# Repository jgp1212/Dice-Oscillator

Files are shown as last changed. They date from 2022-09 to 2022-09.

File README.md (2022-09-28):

# Dice-Oscillator
A simple pcb design for a 40106 square wave oscillator drone.



NOTE: This Readme is still a work in progress

Control 6 oscillators using 6 potentiometers. 


Additional pins have been exposed to allow for potential vactrol implementations, or maybe you have a potentiometer that doesnt fit the footprint. 
Use cables to solder to these points.


Can be powered by 5-12V, using 5V will output roughly ~4Vpp, while 12V will output a 10Vpp.
Power supply must be center positive, I have blown up several CD40106BE by accident by using center negative by accident.

BOM:
-  1 x CD40106BE IC
  - 

-  1 x 2.1mm Power jack OR 1 x 16 pin eurorackstyle header. USE ONLY ONE OPTION WHEN POWERING.
  - 

-  7 x 10K Ohm Resistors
-  1 x 8.2K Ohm Resistor
-  6 x 10K Potentiometers
-  6 x 4.7uF Capacitors (can be altered for different audio)
-  6 x 2 pin jumpers. OR 6 toggle switches whch can be wired in place of the jumpers.

-  1 x LED
-  1 x 510Ohm Resistor
-  1 x 3.5mm mono jack (WQP-PJ301M-12_JACK from Thonkiconn)
  -

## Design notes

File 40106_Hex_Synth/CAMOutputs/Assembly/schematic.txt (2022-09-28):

Partlist exported from C:/Users/jiyong_park/Documents/EAGLE/projects/40106_Hex_Synth/schematic.sch at 16/09/2022 11:22 PM

Qty Value          Device                          Package                    Parts                          Description                                                                                                     AVAILABILITY DESCRIPTION                                               MF                MP        PACKAGE                   POPULARITY PRICE PROD_ID    PURCHASE-URL                                               SF_SKU    VALUE
6                  C5/5                            C5B5                       C1, C2, C3, C4, C5, C6         CAPACITOR                                                                                                                                                                                                                                    1                                                                                                     
8                  CONN_02                         1X02                       J1, J2, J3, J4, J5, J6, J7, J8 Multi connection point. Often used as Generic Header-pin footprint for 0.1 inch spaced/style header connections                                                                                                                                                                                                                                    
6                  CONN_03                         1X03                       J9, J10, J11, J12, J13, J14    Multi connection point. Often used as Generic Header-pin footprint for 0.1 inch spaced/style header connections                                                                                                                                                                                                                                    
1                  LED5MM                          LED_5MM                    D2                             LED (Generic)                                                                                                                                                                                                                                                                                                                                      
1                  SWITCH-SPDT-PTH-11.6X4.0MM      SWITCH_SPDT_PTH_11.6X4.0MM S1                             Single Pole, Double Throw (SPDT) Switch                                                                                                                                                                                                                       SWCH-08261                                                            COM-00102      
2                  RESISTORAXIAL-0.3               AXIAL-0.3                  8.2K, 510OHM                   Generic Resistor Package                                                                                                                                                                                                                                                                                                                           
7   10k            10KOHM-HORIZ-1/4W-1%            AXIAL-0.3                  R1, R2, R3, R4, R5, R6, R7     10kΩ resistor                                                                                                                                                                                                                                                 RES-12183                                                                       10k  
6   10k            POTENTIOMETER-PTH-9MM-1/20W-20% POT-PTH-ALPS               VR1, VR2, VR3, VR4, VR5, VR7   Potentiometer (Pot)                                                                                                                                                                                                                                           RES-09177                                                             COM-09288 10k  
1   CD40106BE      CD40106BE                       DIP794W45P254L1969H508Q14  U1                             Check availability                                                                                              In Stock      6-ch, 3-V to 18-V inverters with Schmitt-Trigger inputs  Texas Instruments CD40106BE PDIP-14 Texas Instruments            None             https://pricing.snapeda.com/search/part/CD40106BE/?ref=eda                
1   POWER_JACK     POWER_JACK                      POWER_JACK_PTH             J15                            Power Jack Connector                                                                                                                                                                                                                                          CONN-08197                                                                           
1   POWER_SIMPLE16 POWER_SIMPLE16                  POWER_16                   U$1

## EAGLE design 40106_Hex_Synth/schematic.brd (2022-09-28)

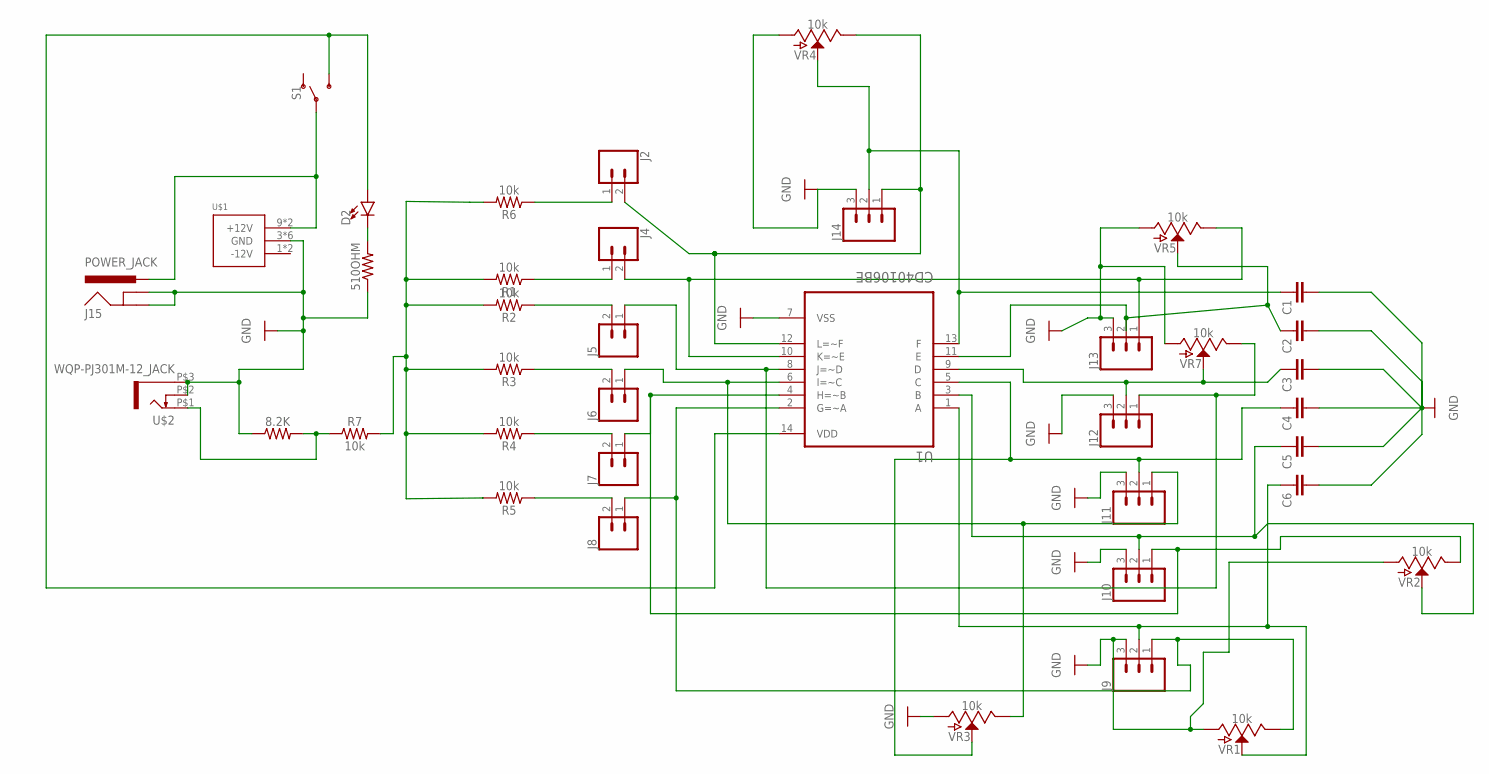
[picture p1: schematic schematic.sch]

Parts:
8.2K, 510OHM: AXIAL-0.3
C1, C2, C3, C4, C5, C6: C5/5; C5B5
D2: LED5MM; LED_5MM
J2, J4, J5, J6, J7, J8: CONN_02; 1X02
J9, J10, J11, J12, J13, J14: CONN_03; 1X03
J15: POWER_JACK; POWER_JACK_PTH
R1, R2, R3, R4, R5, R6, R7: 10k; AXIAL-0.3
S1: SWITCH-SPDT-PTH-11.6X4.0MM; SWITCH_SPDT_PTH_11.6X4.0MM
U1: CD40106BE; DIP794W45P254L1969H508Q14
U$1: POWER_SIMPLE16; POWER_16
U$2: WQP-PJ301M-12_JACK
VR1, VR2, VR3, VR4, VR5, VR7: 10k; POT-PTH-ALPS

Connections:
GND: 8.2K.P$1 (1), 510OHM.P$1 (1), C1.2, C2.2, C3.2, C4.2, C5.2, C6.2, J9.3, J10.3, J11.3, J12.3, J13.3, J14.3, J15.GND, J15.GNDBREAK, U1.7 (VSS), U$1.3 (GND), U$1.4 (GND), U$1.5 (GND), U$1.6 (GND), U$1.7 (GND), U$1.8 (GND), U$2.P$2 (3), U$2.P$3 (1), VR1.P$3 (A), VR2.P$3 (A), VR3.P$3 (A), VR4.P$3 (A), VR5.P$3 (A), VR7.P$3 (A)
unnamed: 510OHM.P$2 (2), D2.K (C)
unnamed: C1.1, J14.2, U1.13 (F), VR4.P$2 (S)
unnamed: J2.2, J14.1, U1.12 (L=~F), VR4.P$1 (E)
unnamed: J4.1, R1.P$1 (1)
unnamed: J5.1, J12.1, U1.8 (J=~D), VR7.P$1 (E)
unnamed: C4.1, J11.2, U1.5 (C), VR3.P$2 (S)
unnamed: C5.1, J10.2, U1.3 (B), VR2.P$2 (S)
unnamed: C6.1, J9.2, U1.1 (A), VR1.P$2 (S)
unnamed: C2.1, J13.2, U1.11 (E), VR5.P$2 (S)
unnamed: J5.2, R2.P$1 (1)
unnamed: J8.2, R5.P$1 (1)
unnamed: J7.2, R4.P$1 (1)
unnamed: J6.2, R3.P$1 (1)
unnamed: J2.1, R6.P$1 (1)
unnamed: J4.2, J13.1, U1.10 (K=~E), VR5.P$1 (E)
unnamed: C3.1, J12.2, U1.9 (D), VR7.P$2 (S)
unnamed: J6.1, J11.1, U1.6 (I=~C), VR3.P$1 (E)
unnamed: J7.1, J10.1, U1.4 (H=~B), VR2.P$1 (E)
unnamed: J8.1, J9.1, U1.2 (G=~A), VR1.P$1 (E)
unnamed: 8.2K.P$2 (2), R7.P$1 (1), U$2.P$1 (2)
unnamed: R1.P$2 (2), R2.P$2 (2), R3.P$2 (2), R4.P$2 (2), R5.P$2 (2), R6.P$2 (2), R7.P$2 (2)
unnamed: J15.PWR, S1.2, U$1.9 (+12V), U$1.10 (+12V)
unnamed: D2.A, S1.3 (S), U1.14 (VDD)

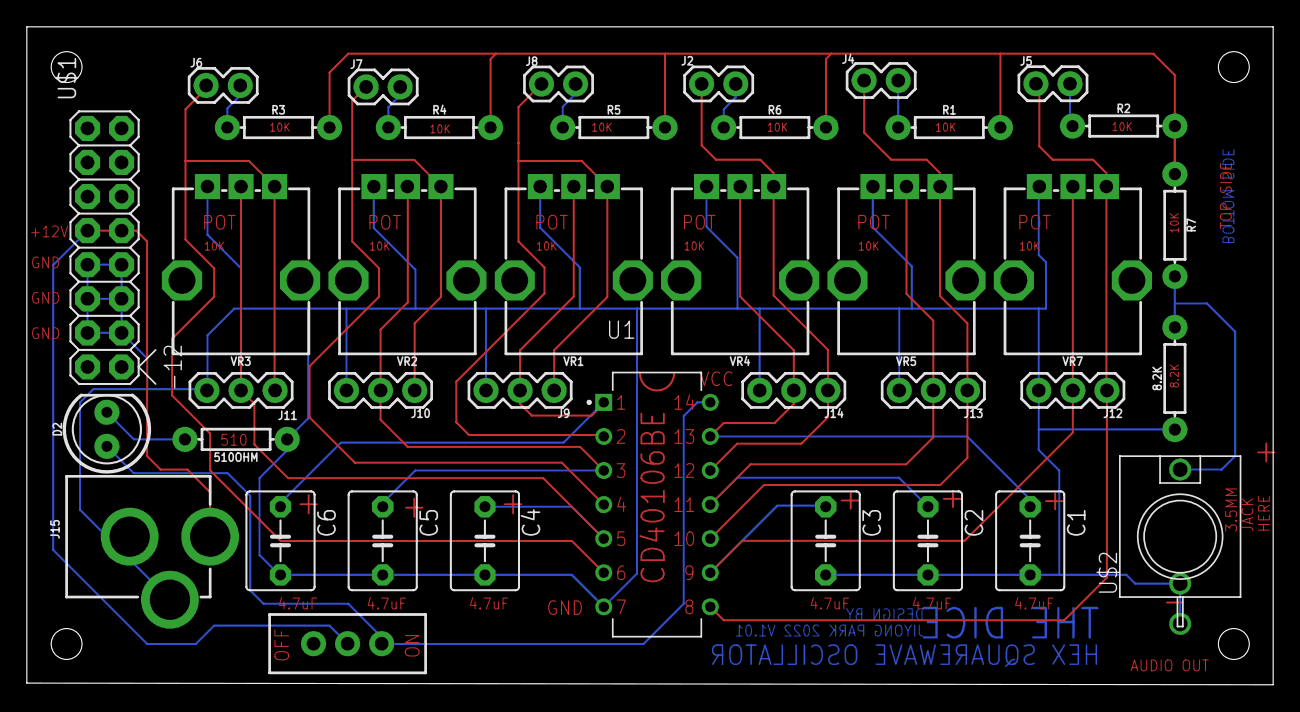
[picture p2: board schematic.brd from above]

Board: 2 copper layers, 92.9 x 49.0 mm, 39 parts (0 on the bottom side), 24 nets.

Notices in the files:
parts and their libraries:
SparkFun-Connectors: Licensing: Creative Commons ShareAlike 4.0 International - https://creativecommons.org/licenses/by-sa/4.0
